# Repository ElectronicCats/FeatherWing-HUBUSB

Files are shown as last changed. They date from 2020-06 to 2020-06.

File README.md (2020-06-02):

# WingHub

## License
Electronic Cats invests time and resources providing this open source design, please support Electronic Cats and open-source hardware by purchasing products from Electronic Cats!

Designed by Electronic Cats.

Firmware released under an GNU AGPL v3.0 license. See the LICENSE file for more information.

Hardware released under an CERN Open Hardware Licence v1.2. See the LICENSE_HARDWARE file for more information.

Electronic Cats is a registered trademark, please do not use if you sell these PCBs.

Jun 2020

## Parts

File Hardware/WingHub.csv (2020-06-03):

Reference | Value | Footprint | Datasheet | Mfr.Part # | Price | Vendor
U1 | CH559T | Package_SO:SSOP-20_5.3x7.2mm_P0.65mm | https://datasheet.lcsc.com/szlcsc/1808111011_WCH-Jiangsu-Qin-Heng-CH559T_C85215.pdf | CH559T | $1.1231 | LSCS
C1 | 0.1uF | Capacitor_SMD:C_0805_2012Metric | ~ | CL21F104ZBCNNNC | $0.0099 | LSCS
C2 | 3.3uF | Capacitor_SMD:C_0805_2012Metric | ~ | 0805X335K250CT | $0.031592 | LSCS
SW2 | DOWNLOADER | Button_Switch_SMD:SW_SPST_TL3342 | ~ | TS5215A 250gf | $0.0148 | LSCS
SW1 | RESET | Button_Switch_SMD:SW_SPST_TL3342 | ~ | TS5215A 250gf | $0.0148 | LSCS
J1 | feather long | Connector_PinHeader_2.54mm:PinHeader_1x16_P2.54mm_Vertical | ~
J2 | feather short | Connector_PinHeader_2.54mm:PinHeader_1x12_P2.54mm_Vertical | ~
J3 | USB_A | Connector_USB:USB_A_CONNFLY_DS1095-WNR0 | ~ | C42643 | $0.0334 | LCSC
D1 | LED | LED_SMD:LED_0805_2012Metric | ~ | D-R080508L3-KS2 | $0.015256 | LSCS
R1 | 1K | Resistor_SMD:R_0805_2012Metric | ~ | 0805W8J0102T5E | $0.001866 | LSCS

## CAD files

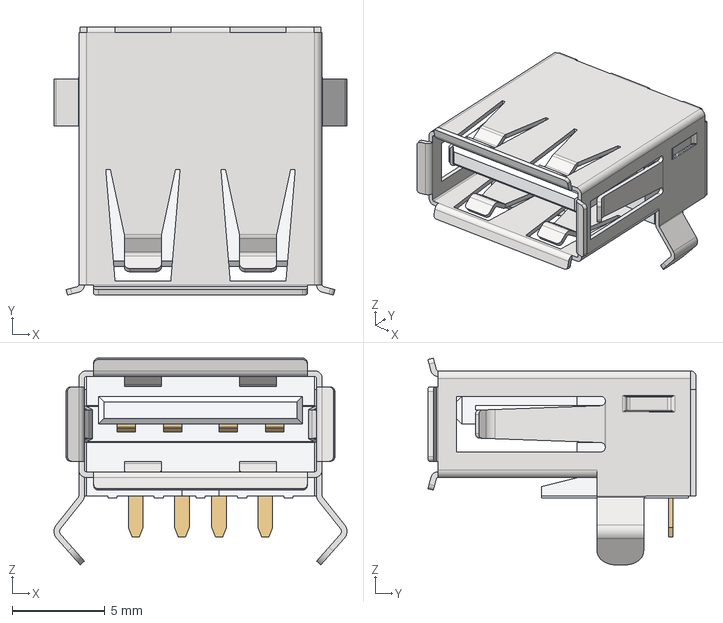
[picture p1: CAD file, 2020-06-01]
Hardware/femaleThruHoleUSB.stp
15.8 x 14.4 x 11.1 mm

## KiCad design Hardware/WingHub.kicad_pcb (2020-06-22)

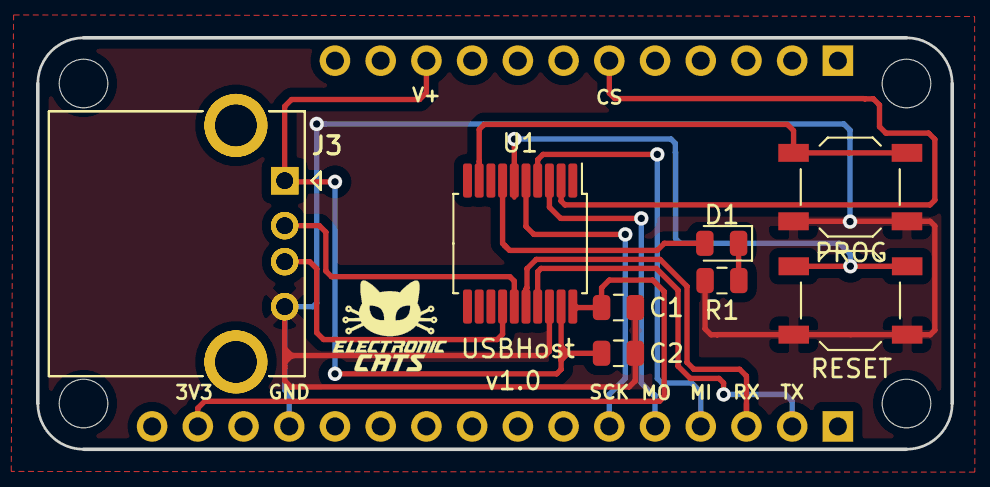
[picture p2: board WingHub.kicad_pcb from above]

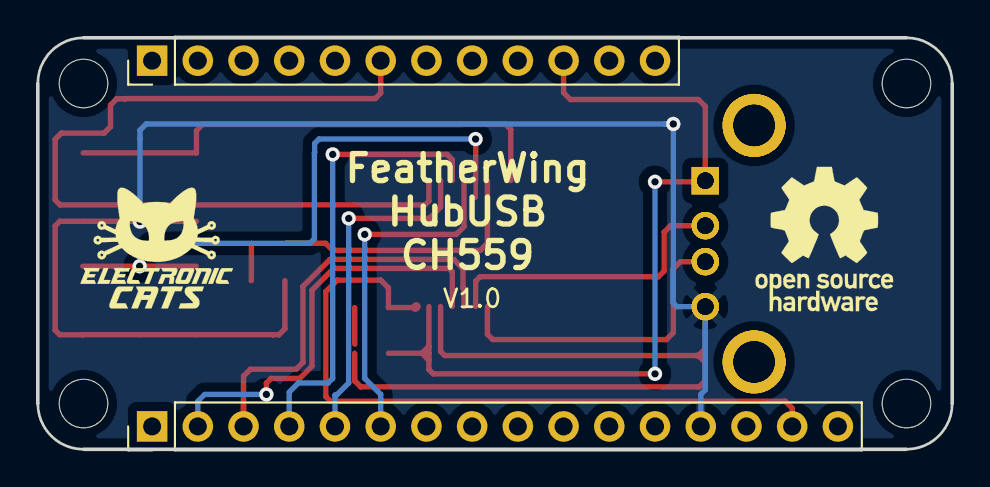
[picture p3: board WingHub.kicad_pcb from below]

Board: 2 copper layers, 50.8 x 22.9 mm, 11 parts (2 on the bottom side), 16 nets.

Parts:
C1: 0.1uF; C_0805_2012Metric
C2: 3.3uF; C_0805_2012Metric
D1: LED; LED_0805_2012Metric
J1: feather long; PinHeader_1x16_P2.54mm_Vertical
J2: feather short; PinHeader_1x12_P2.54mm_Vertical
J3, J3#2: USB_A; USB_A_CONNFLY_DS1095-WNR0
PROG: DOWNLOADER; SW_SPST_TL3342
R1: 1K; R_0805_2012Metric
RESET: RESET; SW_SPST_TL3342
U1: CH559T; SSOP-20_5.3x7.2mm_P0.65mm

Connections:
+3V3: C1.1, J1.15, U1.20
/CS: J2.6, U1.2
/D+: J3.3, J3#2.3, U1.14
/D-: J3.2, J3#2.2, U1.15
/LED: D1.2, U1.7
/MISO: J1.4, U1.4
/MOSI: J1.5, U1.3
/PROG: PROG.1, U1.9
/RST: RESET.1, U1.6
/RX: J1.3, U1.16
/SCK: J1.6, U1.5
/TX: J1.2, U1.17
GND: C1.2, C2.2, J1.13, J3.4, J3#2.4, PROG.2, R1.2, RESET.2, U1.18
unnamed: D1.1, R1.1
unnamed: J3.5, J3#2.5
VBUS: C2.1, J2.10, J3.1, J3#2.1, U1.19

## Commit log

2020-05-22 Init schematic
    [WingHub.kicad_pcb, WingHub.sch]
2020-05-22 Update Wings format
    [WingHub.kicad_pcb, WingHub.sch]
2020-05-23 TEST Gitkraken
    [WingHub.kicad_pcb, WingHub.sch]
2020-05-23 Update schematic
    [WingHub.kicad_pcb, WingHub.sch]
2020-05-27 CH559L Updated
    [WingHub.sch]
2020-05-28 Pre-routed HUSUSB PCB
    [WingHub.kicad_pcb, WingHub.sch]
2020-05-29 Routed and copper-zone-filled HUSUSB_PCB
    [WingHub.kicad_pcb]
2020-05-29 add SPI and LED serial data
    [WingHub.sch]
2020-05-29 add logos and LED serial data
    [WingHub.kicad_pcb]
2020-05-29 Added electronic devices are routed.
    [WingHub.kicad_pcb]
2020-05-30 Silk screen tags moved
    [WingHub.kicad_pcb]
2020-05-30 add HubUSB 3D Model
    [WingHub.kicad_pcb, femaleThruHoleUSB.stp]
2020-05-30 layers ok
    [WingHub.kicad_pcb]
2020-06-01 Tracers are updated
    [WingHub.kicad_pcb]
2020-06-01 add model USB 3D
    [WingHub.kicad_pcb]
2020-06-01 change tx and rx
    [WingHub.sch]
2020-06-01 fix labels pinout
    [WingHub.kicad_pcb]
2020-06-01 Tx and Rx routes exchanged.
    [WingHub.kicad_pcb]
2020-06-01 labels buttons
    [WingHub.kicad_pcb]
2020-06-02 WingHubBom.ods created with plugin.
    [WingHub.kicad_pcb, WingHubbom.ods]
2020-06-03 Firmware folder and WingHub.csv (BOM) created.
    [WingHub.csv, WingHub.sch, WingHubbom.ods]
2020-06-22 Hardware changes added
    [WingHub.kicad_pcb]
